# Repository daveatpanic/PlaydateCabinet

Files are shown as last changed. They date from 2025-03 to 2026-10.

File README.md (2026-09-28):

# Playdate Cabinet
CAD and code for the Playdate Cabinet

	mirrorpi/ - Mirror port for the Raspberry Pi
	crank/ - KiCad files for crank sensor PCB, Arduino sketch for Seeeduino Xiao controller
	cabinet.skp - SketchUp CAD file for cabinet

Build the cabinet version with `make -C mirrorpi rpi`, or the physical-Playdate-controller version with `make -C mirrorpi rpi-no-controls`. The latter accepts `--viewport=x,y,width,height` for an optional destination rectangle, for example:

	./mirrorpi/mirror-no-controls --viewport=40,48,640,384

BOM

	Display: Scepter ‎E205W-16003R 20" 1600x900 75Hz Ultra Thin LED Monitor
	Raspberry Pi 3 B+
	EG STARTS JXGF-5Pin-Stick Arcade Joystick
	3x Reyann Black Happ Type Standard Arcade Push Button with Microswitch

Paint: Rustoleum Painter's Touch 2x Golden Sunset

raspi-config: enable serial, but not login over serial

add `dwc_otg.speed=1 video=HDMI-A-1:1280x720M@60` to cmdline.txt

add

	hdmi_group=1
	hdmi_drive=2

to [all] in config.txt, create /etc/asound.conf:

	defaults.pcm.card 1
	defaults.ctl.card 1

do crontab -e, add

	@reboot /home/pi/runmirror.sh

_Playdate Cabinet is a side project, not a Panic product! Please email dave@panic.com with questions, not Playdate support!_

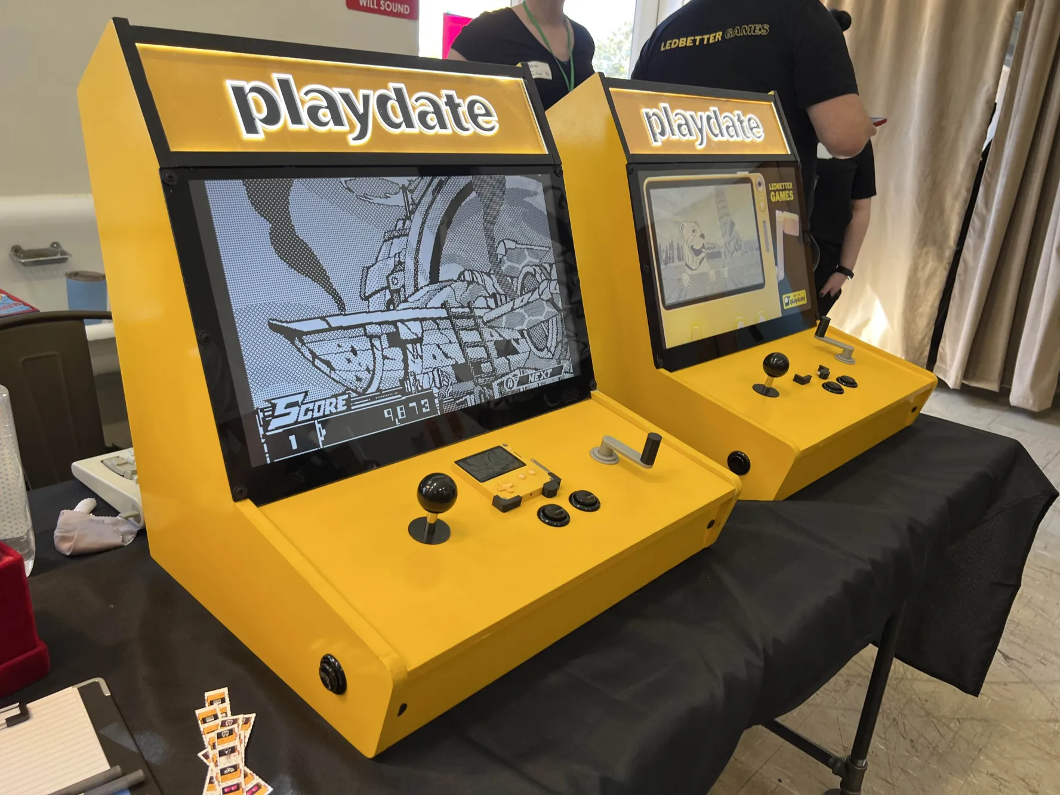
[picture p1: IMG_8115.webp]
Playdate cabinets at Fantastic Arcade 2024 Cabinets


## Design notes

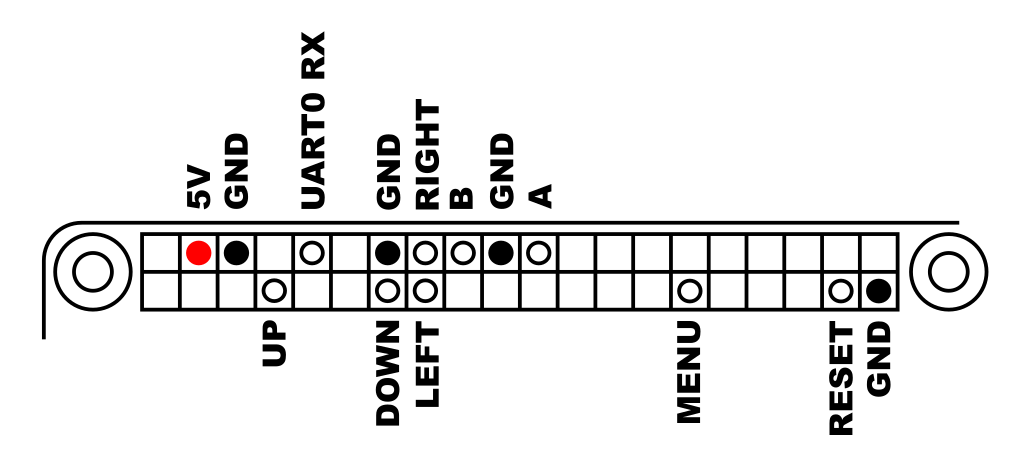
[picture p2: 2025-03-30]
rpi-pinout@2x.png

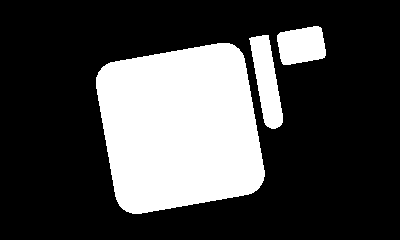
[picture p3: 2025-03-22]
image.png

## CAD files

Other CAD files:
cabinet.skp

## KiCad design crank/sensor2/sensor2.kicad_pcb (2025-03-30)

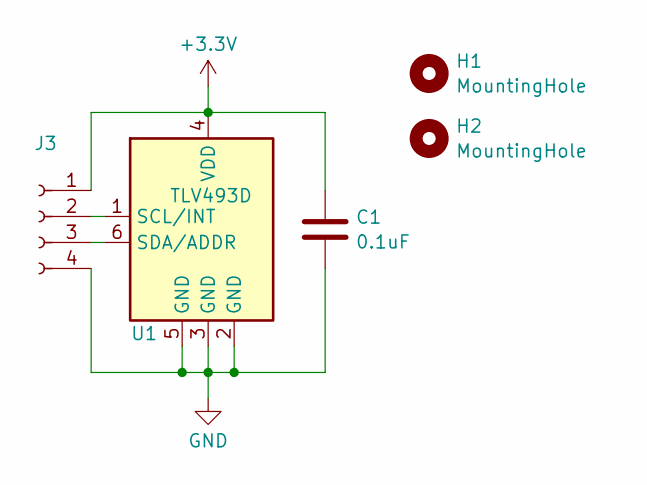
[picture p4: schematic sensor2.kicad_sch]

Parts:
C1: 0.1uF; C_0603_1608Metric
H1, H2: MountingHole; MountingHole_2mm
J3: Conn_01x04_Socket; PinSocket_1x04_P2.54mm_Vertical
U1: TLV493D; SOT-23-6

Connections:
+3.3V: C1.1, J3.1, U1.4 (VDD)
GND: C1.2, J3.4, U1.2 (GND), U1.3 (GND), U1.5 (GND)
unnamed: J3.2, U1.1 (SCL/INT)
unnamed: J3.3, U1.6 (SDA/ADDR)

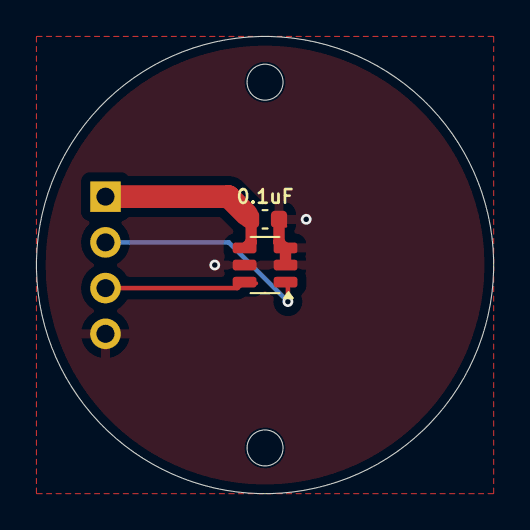
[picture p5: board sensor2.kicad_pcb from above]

Board: 2 copper layers, 25.4 x 25.4 mm, 5 parts (1 on the bottom side), 4 nets.

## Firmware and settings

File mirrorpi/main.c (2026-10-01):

//
//  main.c
//  MirrorJr
//
//  Created by Dave Hayden on 9/25/24.
//

#include <stdio.h>
#include <unistd.h>
#include <time.h>
#include <pthread.h>
#include <errno.h>
#include <sys/types.h>
#include <pwd.h>
#include <grp.h>
#include <netinet/in.h>

#include "SDL.h"

#include "frame.h"
#include "audio.h"
#include "stream.h"
#include "serial.h"
#ifndef MIRRORPI_NO_CONTROLS
#include "controls.h"
#endif

bool checkExit()
{
	SDL_Event event;
	
	if ( SDL_PollEvent(&event) )
	{
		if ( event.type == SDL_QUIT )
			return true;
//		else if ( event.type != SDL_WINDOWEVENT )
//			printf("unhandled event type 0x%x\n", event.type);
	}
	
	return false;
}

void* copySerialToRingbuffer(void* ud);

int bytesread = 0;
time_t starttime;
bool serial_running = false;

/*
static void droproot()
{
	const char* username = "dave";
	struct passwd *pw = getpwnam(username);
	
	if (initgroups(pw->pw_name, pw->pw_gid) != 0 ||
	   setgid(pw->pw_gid) != 0 || setuid(pw->pw_uid) != 0) {
			fprintf(stderr, "droproot: Couldn't change to '%.32s' uid=%lu gid=%lu: %s\n",
				username, 
				(unsigned long)pw->pw_uid,
				(unsigned long)pw->pw_gid,
				strerror(errno));
			exit(1);
	}
}
*/

int get_ip_address(char *ip_buffer);

static bool parseViewport(const char* argument, SDL_Rect* viewport)
{
	char trailing;

	if ( sscanf(argument, "--viewport=%d,%d,%d,%d%c", &viewport->x, &viewport->y, &viewport->w, &viewport->h, &trailing) != 4 )
		return false;

	return viewport->x >= 0 && viewport->y >= 0 && viewport->w > 0 && viewport->h > 0;
}

int main(int argc, const char * argv[])
{
	SDL_Rect viewport;
	const SDL_Rect* viewport_ptr = NULL;

	if ( argc == 2 )
	{
		if ( !parseViewport(argv[1], &viewport) )
		{
			fprintf(stderr, "usage: %s [--viewport=x,y,width,height]\n", argv[0]);
			return -1;
		}

		viewport_ptr = &viewport;
	}
	else if ( argc != 1 )
	{
		fprintf(stderr, "usage: %s [--viewport=x,y,width,height]\n", argv[0]);
		return -1;
	}

	if ( SDL_InitSubSystem(SDL_INIT_VIDEO) != 0 )
	{
		printf("video init failed: %s", SDL_GetError());
		return false;
	}

/*
	int numModes = SDL_GetNumDisplayModes(0);
	for ( int i = 0; i < numModes; ++i )
	{
		SDL_DisplayMode mode;
		
		if ( SDL_GetDisplayMode(0, i, &mode) == 0 )
			printf("mode %i: fmt=%x w=%i h=%i refresh=%i\n", i, mode.format, mode.w, mode.h, mode.refresh_rate);
		else
			printf("Couldn't get display mode %i\n", i);
	}
*/
	
#if TARGET_MACOS
	SDL_Window* window = SDL_CreateWindow("Playdate", SDL_WINDOWPOS_UNDEFINED, SDL_WINDOWPOS_UNDEFINED, 1200, 720, SDL_WINDOW_OPENGL | SDL_WINDOW_SHOWN);
#else
	SDL_Window* window = SDL_CreateWindow("Playdate", SDL_WINDOWPOS_CENTERED, SDL_WINDOWPOS_CENTERED, 1280, 720, SDL_WINDOW_OPENGL | SDL_WINDOW_FULLSCREEN);
#endif
	
	if ( window == NULL )
	{
		printf("couldn't create window: %s\n", SDL_GetError());
		return -1;
	}

	SDL_ShowCursor(SDL_DISABLE);
	
	#ifndef MIRRORPI_NO_CONTROLS
	if ( !controls_init() )
	{
		printf("error initializing control i/o\n");
		return -1;
	}
	#endif
	
	if ( !stream_init() )
	{
		printf("error initializing stream input\n");
		return -1;
	}
	
	if ( !frame_init(window, viewport_ptr) )
		return -1;
	
	audio_init();
	//droproot();
	
	uint8_t ipaddr[INET_ADDRSTRLEN] = "....";
	get_ip_address((char*)ipaddr);
	frame_showWaitScreen(ipaddr);

	for ( ;; )
	{
		printf("waiting for playdate..\n");
	
		frame_showWaitScreen(ipaddr);

		printf("checking serial port\n");

		while ( !ser_isOpen() )
		{
//			printf("checking exit signal\n");

			if ( checkExit() )
				return 0;
			
			usleep(10000);

//			printf("calling ser_open()\n");
			ser_open();
		}
		
		printf("connected!\n");
		stream_begin();
	
		pthread_attr_t attrs;
		pthread_attr_init(&attrs);
	
//		struct sched_param sched = {.sched_priority=50};
//		pthread_attr_setschedparam(&attrs, &sched);
		
		serial_running = true;
		
		pthread_t readthread;
		pthread_create(&readthread, &attrs, copySerialToRingbuffer, NULL);
		
		pthread_attr_destroy(&attrs);
		
		time_t lastpoke = 0;
		starttime = time(NULL);
		
		while ( ser_isOpen() )
		{
			if ( checkExit() )
				return 0;
			
			time_t now = time(NULL);
			
			if ( now > lastpoke )
			{
				stream_poke();
				lastpoke = now;
				
				if ( now > starttime )
					; //printf("%i bytes read, %f kB/s\n", bytesread, (float)bytesread/(now-starttime)/1024.0f);
			}
			
			stream_process();
			#ifndef MIRRORPI_NO_CONTROLS
			controls_scan();
			#endif
			usleep(1000);
		}
		
		audio_stop();
		stream_reset();
		
		serial_running = false;
		pthread_join(readthread, NULL);
	}
	
	return 0;
}

void* copySerialToRingbuffer(void* ud)
{
	printf("serial monitor started..\n");

	//FILE* log = fopen("log.bin", "w");
		
	while ( serial_running )
	{
		static uint8_t buf[65536];
		ssize_t n = ser_read(buf, sizeof(buf));
		
		if ( n > 0 )
		{
//			fwrite(buf, 1, (size_t)n, log);
//			fflush(log);

			bytesread += n;
			stream_addData(buf, (unsigned)n);
		}
		else if ( n < 0 )
		{
			printf("ser_read returned %i errno=%i\n", (int)n, errno);
			break;
		}
	}
	
	printf("serial monitor ended..\n");
	return NULL;
}

#include <string.h>
#include <sys/ioctl.h>
#include <net/if.h>
#include <arpa/inet.h>
#include <unistd.h>

int get_ip_address(char *ip_buffer)
{
	int fd;
	struct ifreq ifr;
	
	// Create a socket to retrieve information about the interface
	fd = socket(AF_INET, SOCK_DGRAM, 0);
	if (fd == -1) {
		perror("Socket creation failed");
		return -1;
	}

	strncpy(ifr.ifr_name, "wlan0", IFNAMSIZ-1);
	ifr.ifr_name[IFNAMSIZ-1] = '\0';

	// Perform an ioctl call to get the IP address of the interface
	if (ioctl(fd, SIOCGIFADDR, &ifr) == -1) {
		perror("ioctl failed");
		close(fd);
		return -1;
	}

	// Convert the IP address to a string and store it in ip_buffer
	struct sockaddr_in *ip_addr = (struct sockaddr_in *)&ifr.ifr_addr;
	strncpy(ip_buffer, inet_ntoa(ip_addr->sin_addr), INET_ADDRSTRLEN);

	// Clean up and return success
	close(fd);
	return 0;
}

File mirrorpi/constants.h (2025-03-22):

#define VENDOR_NAME "Panic"
#define APP_NAME "mirror" // file names, keys, etc.
#define APP_DISPLAY "Mirror" // user display, window titles

#define FRAME_WIDTH      400
#define FRAME_HEIGHT     240
#define ROW_SIZE_BYTES   (FRAME_WIDTH/8)
#define FRAME_SIZE_BYTES (ROW_SIZE_BYTES * FRAME_HEIGHT)

#define NUM_BUTTONS 8

#define BLACK_R 0x31
#define BLACK_G 0x2f
#define BLACK_B 0x28

#define WHITE_R 0xb1
#define WHITE_G 0xaf
#define WHITE_B 0xa8

#define YELLOW_R 0xfb
#define YELLOW_G 0xc6
#define YELLOW_B 0x51

#define COLOR_TRIPLE(color) color##_R, color##_G, color##_B

enum {
	TIMER_StreamProtocolEnable = 1,
	TIMER_StreamProtocolStart = 2,
	TIMER_StreamProtocolPoke = 3,
	TIMER_GameControllerHandlerPoll = 4,
	TIMER_InputHandlerSendUpdate = 5,
};

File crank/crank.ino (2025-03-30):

#include <Wire.h>

bool i2cread(int addr, uint8_t* buf, int count)
{
  int n = Wire.requestFrom(addr, count);

  if ( n < count )
    return false;

  int i;

  for ( i = 0; i < count && Wire.available(); ++i )
  {
    buf[i] = Wire.read();
 //    Serial.print(buf[i], HEX);
 //    Serial.print(" ");
  }

  if ( i < count )
    return false;

  // Serial.println("");

  return true;
}

bool i2cwrite(int addr, uint8_t* buf, int count)
{
  bool ret;

  Wire.beginTransmission(addr);
  ret = (Wire.write(0x00) == 1 && Wire.write(buf, count) == count);
  Wire.endTransmission();

  return ret;
}


bool tryCrank(int addr)
{
  uint8_t buf[10];

  if ( !i2cread(addr, buf, 10) )
  {
    Serial.println("i2cread failed");
    return false;
  }

  buf[0] = (buf[7] & 0x78) | 0x01;
  buf[1] = buf[8];
  buf[2] = (buf[9] & 0x1f) | 0x40;

  if ( !i2cwrite(addr, buf, 3) )
  {
    Serial.println("write failed");
    return false;
  }
  
  if ( !i2cread(addr, buf, 10) )
  {
    Serial.println("i2cread #2 failed");
    return false;
  }

  return true;
}


#define CRANK1_POWER 3
#define CRANK2_POWER 2

#define CRANK1_ADDR 0x5e //if SDA high at boot
#define CRANK2_ADDR 0x1f //if SDA low at boot

void initCranks()
{
  // crank 1 is on xiao's 3v3 line, and SDA is on a pullup, so it'll have address 0x5e
  // then we set SDA low, turn on crank 2, and it should have address 0x1f

  pinMode(CRANK2_POWER, OUTPUT);
  digitalWrite(CRANK2_POWER, LOW);

  pinMode(4,OUTPUT);
  digitalWrite(4, LOW); // set SDA low

  delay(10);

  digitalWrite(CRANK2_POWER, HIGH); // turn on crank 2
  delay(1); // at least 200 uS for address set

  // set SDA and SCL to inputs
  pinMode(4,INPUT);
  pinMode(5,INPUT);

  pinMode(CRANK1_POWER,OUTPUT);
  digitalWrite(CRANK1_POWER, HIGH);

  delay(100);
  // init i2c
  Wire.begin();
  Serial.println("wire.begin() begun");

  Serial.println("looking for cranks..");
  
  if ( tryCrank(CRANK1_ADDR) )
    Serial.println("crank 1 (0x53) found");
  else
    Serial.println("crank 1 (0x53) not found :( :( :(");

  if ( tryCrank(CRANK2_ADDR) )
    Serial.println("crank 2 (0x1f) found");
  else
    Serial.println("crank 2 (0x1f) not found :( :( :(");
}

void setup()
{
  Serial1.begin(115200);
  Serial.begin(9600);
  delay(2000); // 

  initCranks();
}

struct crank
{
  int addr;
  float startangle;
  float lastangle;
  float xavg;
  float yavg;
  bool handlepresent;
};

struct crank crank1 = { .addr = CRANK1_ADDR, .startangle = -1 };
struct crank crank2 = { .addr = CRANK2_ADDR, .startangle = -1 };

#define CRANK_SMOOTH_THRESHOLD 10 // if x or y changes more than this amount, don't smooth value
#define CRANK_SMOOTHING 10 // but for smaller movement we need to average out the noise

// below this amount of angle change, system reports no change
#define CRANK_THRESHOLD 0.8f

// rate limit our reporting so we don't overwhelm the poor Pi
#define REPORT_PERIOD 50

bool sampleCrankSensor(struct crank* crank)
{
  int8_t buf[5];

#define ABS(x) (((x)>=0)?(x):-(x))
#define MAX(x,y) (((x)>(y))?(x):(y))

  if ( !i2cread(crank->addr, (uint8_t*)buf, 5) )
    return false;

  int y = ((int)buf[1] << 4) | (buf[4] & 0xf);
  int x = ((int)buf[0] << 4) | (((uint8_t)buf[4] >> 4) & 0xf);
  
  if ( ABS(y) <= 20 && ABS(x) <= 20 )
  {
    crank->handlepresent = false;
    return true;
  }

  if ( ABS(x-crank->xavg) < CRANK_SMOOTH_THRESHOLD && ABS(y-crank->yavg) < CRANK_SMOOTH_THRESHOLD )
  {
    crank->xavg += (x - crank->xavg) / CRANK_SMOOTHING;
    crank->yavg += (y - crank->yavg) / CRANK_SMOOTHING;
  }
  else
  {
    crank->xavg = x;
    crank->yavg = y;
  }

  crank->handlepresent = true;
  return true;
}

static int count = 0;


void updateCrank(struct crank* crank)
{
    if ( crank->handlepresent )
    {
      float angle = atan2(crank->yavg,-crank->xavg) * 180 / M_PI;

      if ( angle < 0 ) angle += 360;

      if ( crank->startangle == -1 )
      {
        // XXX - need to debounce this
        Serial.println("handle in");
        Serial1.println("in");
        crank->startangle = angle;
        crank->lastangle = 0;
      }

      angle -= crank->startangle;
      if ( angle < 0 ) angle += 360;

      float change = angle - crank->lastangle;
    
      if ( change > 180 )
        change -= 360;
      else if ( change < -180 )
        change += 360;

      if ( ABS(change) > CRANK_THRESHOLD )
      {
        Serial.println(angle, 1);
        Serial1.println(angle, 1);
        crank->lastangle = angle;
      }
    }
    else if ( crank->startangle != -1 )
    {
      Serial.println("handle out");
      Serial1.println("out");
      crank->startangle = -1;
    }
}

void loop()
{
  bool handlepresent;

  if ( !sampleCrankSensor(&crank1) ) Serial.println("crank 1 not found");
  if ( !sampleCrankSensor(&crank2) ) Serial.println("crank 2 not found");

  if ( ++count == REPORT_PERIOD )
  {
    count = 0;
    updateCrank(&crank1);
    updateCrank(&crank2);
  }
/*
  Serial.print(crank1.lastangle);
  Serial.print(" ");
  Serial.println(crank2.lastangle);
  */
}

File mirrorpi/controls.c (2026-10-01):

//
//  controls.c
//  MirrorJr
//
//  Created by Dave Hayden on 9/28/24.
//

#include <stdio.h>
#include <stdlib.h>
#include <unistd.h>
#include <ctype.h>
#include "config.h"
#include "controls.h"
#include "stream.h"

#if TARGET_RPI
#include <pigpio.h>
#endif

// buttons are on the following GPIOs, crank is handled by an external
// microcontroller which sends us movement data over /dev/ttyS0

enum buttons
{
	kButtonUp,
	kButtonDown,
	kButtonLeft,
	kButtonRight,
	kButtonB,
	kButtonA,
	kButtonMenu,
	kButtonDock,
};

#if TARGET_RPI
struct config gpio;
unsigned int crankdev = 0;

int crankpos = 0;
int lastcrank = 0;
bool docked = true;

#define DEBOUNCE_TIME 100
int a_high = 0;
int b_high = 0;

void aFunction(int n, int level, uint32_t tick)
{
	//printf("A:%i\n", level);
	/*
	0 = change to low (a falling edge)
	1 = change to high (a rising edge)
	2 = no level change (a watchdog timeout)
	*/
	
	if ( level == 1 )
	{
		crankpos += b_high ? gpio.rotarymult : -gpio.rotarymult;
		a_high = 1;
	}
	else if ( level == 0 )
	{
		crankpos += b_high ? -gpio.rotarymult : gpio.rotarymult;
		a_high = 0;
	}
	
	crankpos = (crankpos+360)%360;
}

void bFunction(int n, int level, uint32_t tick)
{
	//printf("B:%i\n", level);
	
	if ( level == 1 )
	{
		crankpos += a_high ? -gpio.rotarymult : gpio.rotarymult;
		b_high = 1;
	}
	else if ( level == 0 )
	{
		crankpos += a_high ? gpio.rotarymult : -gpio.rotarymult;
		b_high = 0;
	}
	
	crankpos = (crankpos+360)%360;
}

bool initpin(int pin)
{
	return gpioSetMode((unsigned int)pin, PI_INPUT) == 0 &&
		gpioSetPullUpDown((unsigned int)pin, PI_PUD_UP) == 0 &&
		gpioGlitchFilter((unsigned int)pin, DEBOUNCE_TIME) == 0;
}
#endif

bool controls_init()
{
#if TARGET_RPI
	int res = gpioInitialise();
	get_config(&gpio);

	if ( res < 0 )
	{
		printf("gpioInitialise failed\n");
		return false;
	}

	if ( gpio.rotary1 != -1 && gpio.rotary2 != -1 )
	{
		if ( !initpin(gpio.rotary1) || !initpin(gpio.rotary2) )
		{
			printf("gpioSetMode/PullUpDown failed\n");
			return false;
		}
		
		gpioSetAlertFunc((unsigned int)gpio.rotary1, aFunction);
		gpioSetAlertFunc((unsigned int)gpio.rotary2, bFunction);
	}
	else
	{
		int dev;
		
		if ( (dev = serOpen("/dev/ttyS0", 115200, 0)) < 0 )
		{
			printf("crank init failed\n");
			return false;
		}
			
		crankdev = (unsigned)dev;
	}

	if ( gpio.dock != -1 && !initpin(gpio.dock) )
	{
		printf("gpioSetMode/PullUpDown failed\n");
		return false;
	}

	if ( !initpin(gpio.up) || !initpin(gpio.down) || !initpin(gpio.left) || !initpin(gpio.right) || 
		 !initpin(gpio.b) || !initpin(gpio.a) || !initpin(gpio.menu) )
	{
		printf("gpioSetMode/PullUpDown failed\n");
		return false;
	}
#endif

	return true;
}

int buttonon[8] = {0};

void controls_scan()
{
#if TARGET_RPI
	// XXX - debounce if needed
	
	int* gpios = (int*)&gpio;
	
	for ( int i = 0; i < 7; ++i )
	{
		int on = 1-(int)gpioRead((unsigned int)gpios[i]);
		
		if ( on && !buttonon[i] )
			stream_sendButtonPress(i);
		else if ( !on && buttonon[i] )
			stream_sendButtonRelease(i);
		
		buttonon[i] = on;
	}
	
	float crankangle = -1;
	static float lastangle = -1;
	
	if ( gpio.dock != -1 )
	{
		int on = 1-(int)gpioRead((unsigned int)gpios[kButtonDock]);
		
		if ( on && !buttonon[kButtonDock] )
		{
			docked = !docked;
			stream_sendCrankDocked(docked);

			if ( docked )
			{
				// make sure movement doesn't immediately undock
				crankpos = lastcrank;
				crankangle = lastangle;
			}
		}

		buttonon[kButtonDock] = on;
	}

	if ( gpio.rotary1 != -1 && gpio.rotary2 != -1 )
	{
		if ( docked && crankpos != lastcrank )
		{
			docked = false;
			stream_sendCrankDocked(false);
		}
		
		lastcrank = crankpos;
		crankangle = crankpos;
	}
	else
	{
		static char readbuf[6] = {0};
		static int readpos = 0;
		
		// rate limit the crank
		static int limit = 0;
		
		if ( ++limit < 3 )
			return;
		
		limit = 0;

		while ( serDataAvailable(crankdev) )
		{
			int b = serReadByte(crankdev);
			
			if ( b == '\n' )
			{
				if ( isdigit(readbuf[0]) )
					crankangle = atof(readbuf);
				else if ( readpos == 4 && strncmp(readbuf, "out", 3) == 0 )
					stream_sendCrankDocked(true);
				else if ( readpos == 3 && strncmp(readbuf, "in", 2) == 0 )
					stream_sendCrankDocked(false);
	
				//printf("read %f", crankangle);
				readpos = 0;
			}
			else if ( readpos < 5 )
				readbuf[readpos++] = b;
		}
	}

	if ( crankangle != -1 )
	{
		if ( lastangle != -1 )
		{
			float change = crankangle - lastangle;
			
			if ( change > 180 ) change -= 360;
			else if ( change < -180 ) change += 360;
			
			if ( change != 0 )
			{
				stream_sendCrankChange(change);
				//printf("sending crank change %f\n", change);
			}
		}
		
		lastangle = crankangle;
	}
#endif
}

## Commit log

2025-03-22 moar files!!
    [cabinet.skp, sensor.kicad_sch, sensor2.kicad_pcb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]
2025-03-22 added BOM, sorta
2025-03-28 reset readpos after \n
    [controls.c]
2025-03-30 swapped crank ic power pins
    [crank.ino]
2025-03-30 removed dumb switch, forgot that I could just power the second sensor directly from gpio
    [sensor.kicad_sch]
2025-03-30 added kicad backup folders
2025-03-30 fixed pin mismatch
2025-03-31 wait for A button to be pressed before going into mirror loop
2026-08-11 Add no-controls Raspberry Pi variant and optional viewport
2026-10-01 added config file option for gpio mapping, support for rotary encoder+dock button as alternative to serial crank,
